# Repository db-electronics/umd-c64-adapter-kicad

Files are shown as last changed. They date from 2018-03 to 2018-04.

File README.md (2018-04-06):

# Copyright and Disclaimer
Copyright: René Richard

This documentation describes Open Hardware and is licensed under the
CERN OHL v. 1.2.

You may redistribute and modify this documentation under the terms of the
CERN OHL v.1.2. (http://ohwr.org/cernohl). This documentation is distributed
WITHOUT ANY EXPRESS OR IMPLIED WARRANTY, INCLUDING OF
MERCHANTABILITY, SATISFACTORY QUALITY AND FITNESS FOR A
PARTICULAR PURPOSE. Please see the CERN OHL v.1.2 for applicable
conditions

# C64 UMD Adapter
This KiCad project contains the Commodore 64 cartridge adapter for the [Universal Mega Dumper](https://github.com/db-electronics/Universal-Mega-Dumper).

## ID
* 0x02

Each UMD adapter contains a serial shift register with an 8bit ID.

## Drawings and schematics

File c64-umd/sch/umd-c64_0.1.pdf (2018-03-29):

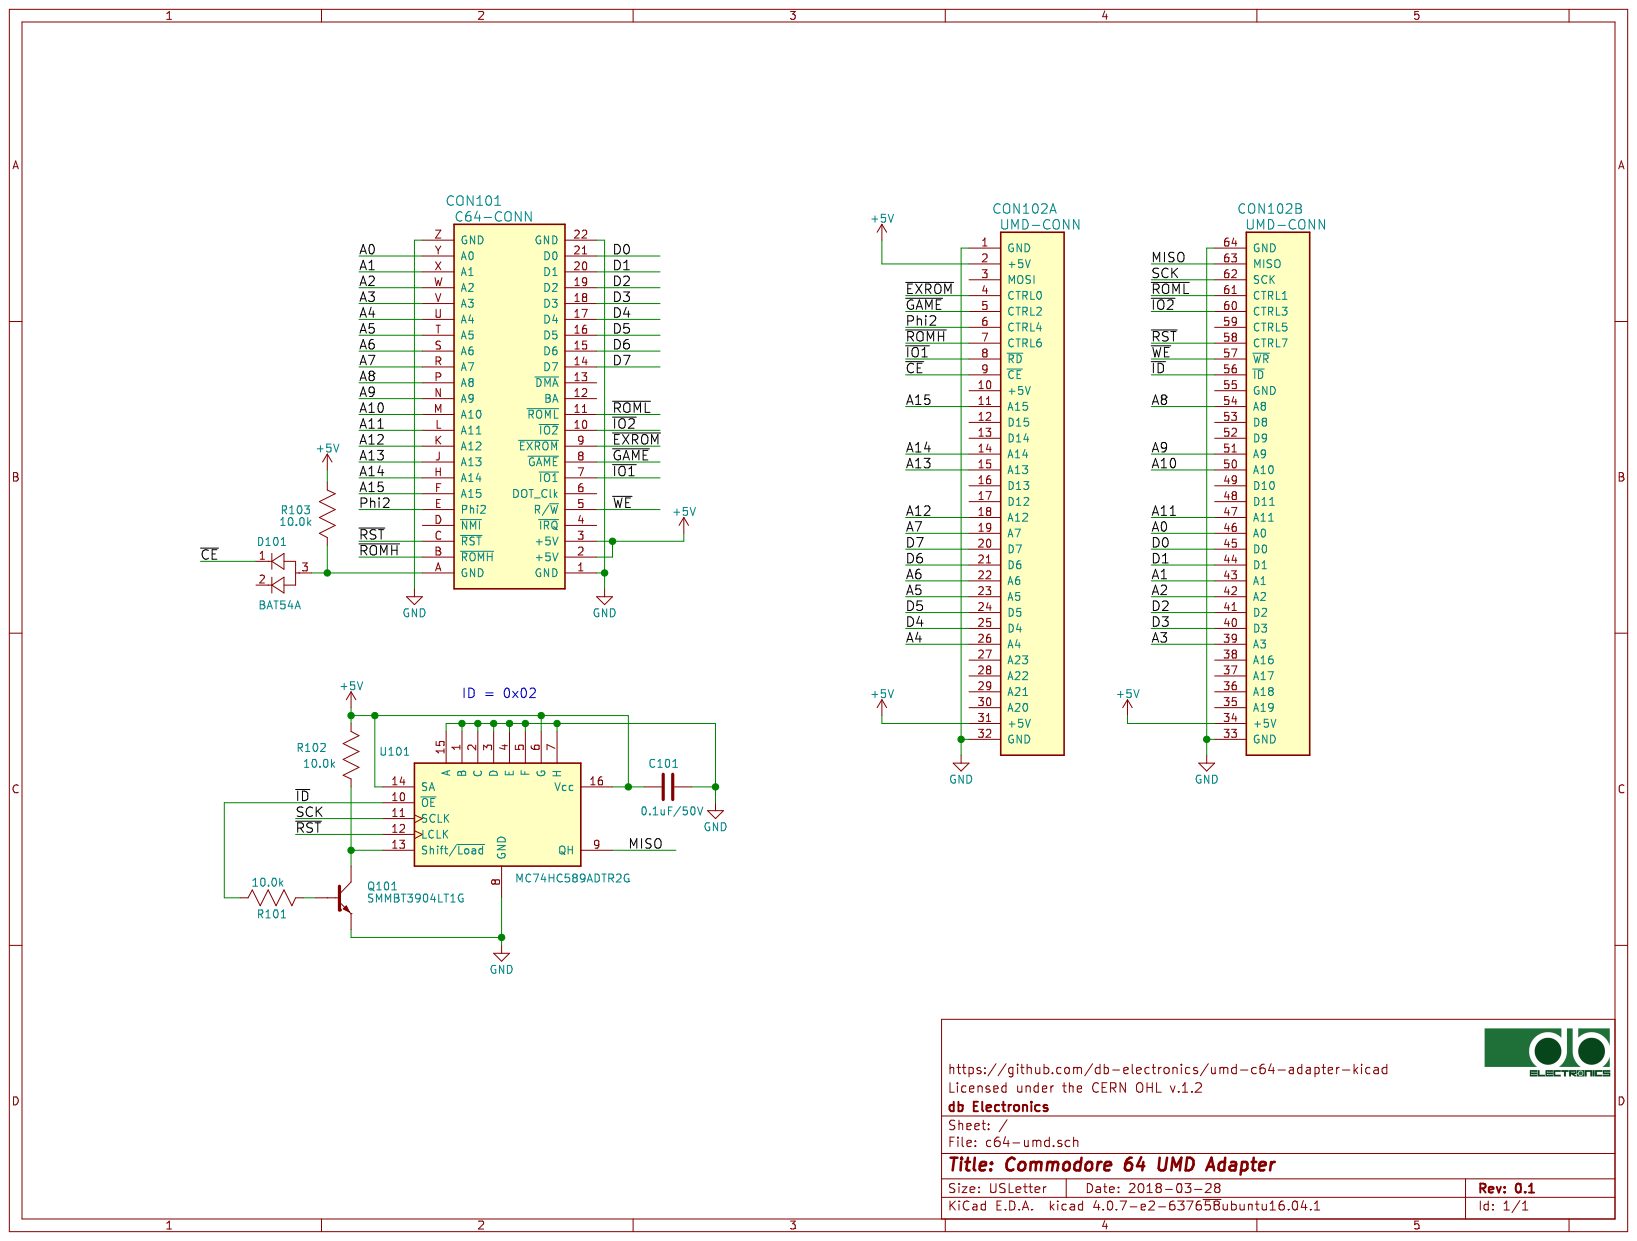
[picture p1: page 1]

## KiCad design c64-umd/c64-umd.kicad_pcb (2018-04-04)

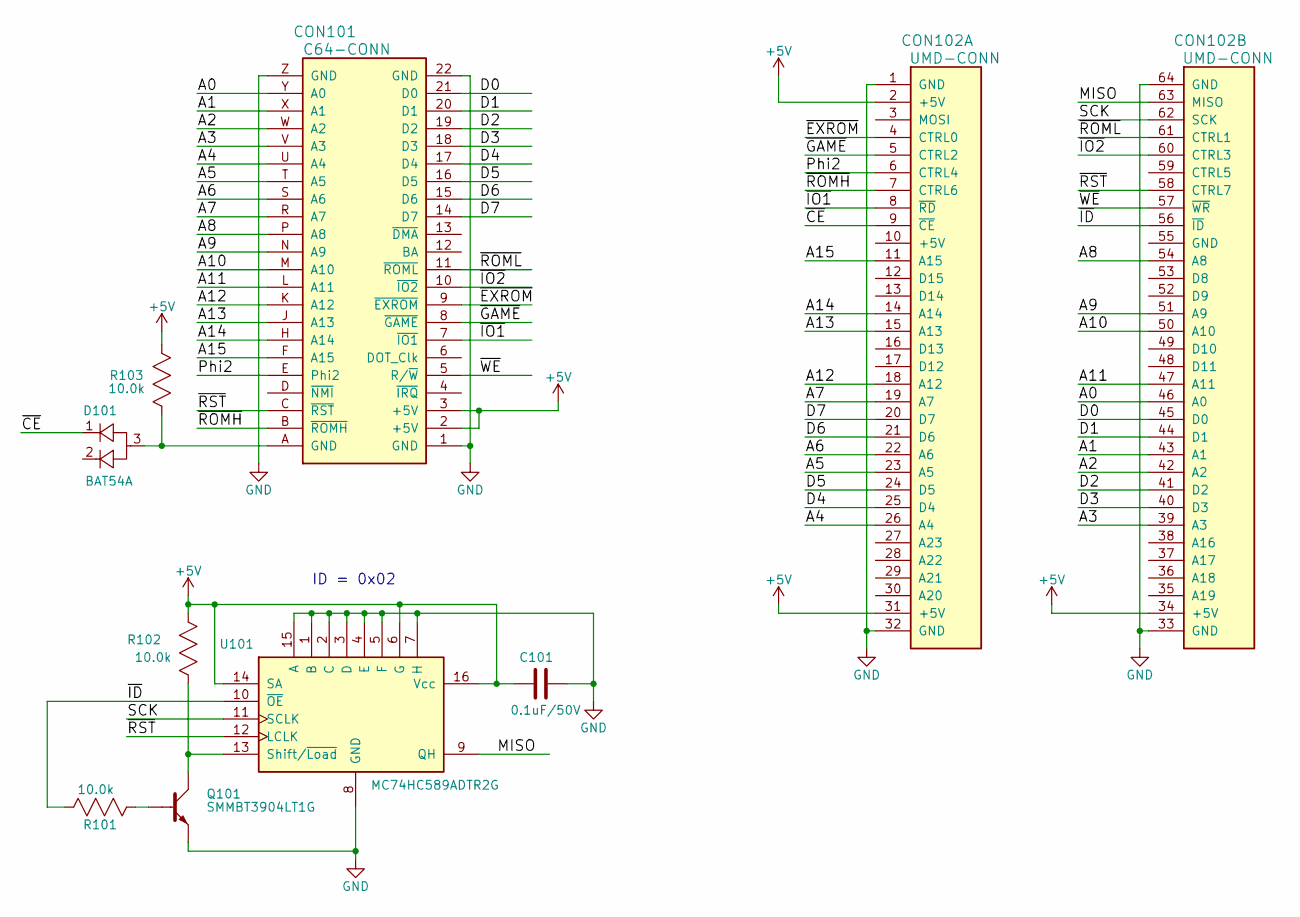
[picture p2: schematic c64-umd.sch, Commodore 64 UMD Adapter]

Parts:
C101: 0.1uF/50V; 0603; Digikey 445-5666-1-ND
CON101: C64-CONN; Digikey #ND
CON102: UMD-CONN; UMD-CONN-DIP64
D101: BAT54A; SOT23; Digikey BAT54AFSCT-ND
Q101: SMMBT3904LT1G; SOT23; Digikey SMMBT3904LT1GOSCT-ND
R101, R102, R103: 10.0k; 0603; Digikey P10.0KHCT-ND
U101: MC74HC589ADTR2G; TSSOP-16; Digikey MC74HC589ADTR2GOSCT-ND

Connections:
+5V: C101.2, CON101.2 (+5V), CON101.3 (+5V), CON102.2 (+5V), CON102.31 (+5V), CON102.34 (+5V), R102.1, R103.1, U101.6 (G), U101.14 (SA), U101.16 (Vcc)
/A0: CON101.Y (A0), CON102.46 (A0)
/A1: CON101.X (A1), CON102.43 (A1)
/A2: CON101.W (A2), CON102.42 (A2)
/A3: CON101.V (A3), CON102.39 (A3)
/A4: CON101.U (A4), CON102.26 (A4)
/A5: CON101.T (A5), CON102.23 (A5)
/A6: CON101.S (A6), CON102.22 (A6)
/A7: CON101.R (A7), CON102.19 (A7)
/A8: CON101.P (A8), CON102.54 (A8)
/A9: CON101.N (A9), CON102.51 (A9)
/A10: CON101.M (A10), CON102.50 (A10)
/A11: CON101.L (A11), CON102.47 (A11)
/A12: CON101.K (A12), CON102.18 (A12)
/A13: CON101.J (A13), CON102.15 (A13)
/A14: CON101.H (A14), CON102.14 (A14)
/A15: CON101.F (A15), CON102.11 (A15)
/D0: CON101.21 (D0), CON102.45 (D0)
/D1: CON101.20 (D1), CON102.44 (D1)
/D2: CON101.19 (D2), CON102.41 (D2)
/D3: CON101.18 (D3), CON102.40 (D3)
/D4: CON101.17 (D4), CON102.25 (D4)
/D5: CON101.16 (D5), CON102.24 (D5)
/D6: CON101.15 (D6), CON102.21 (D6)
/D7: CON101.14 (D7), CON102.20 (D7)
/MISO: CON102.63 (MISO), U101.9 (QH)
/Phi2: CON101.E (Phi2), CON102.6 (CTRL4)
/SCK: CON102.62 (SCK), U101.11 (SCLK)
/~CE: CON102.9 (~CE), D101.1
/~EXROM: CON101.9 (~EXROM), CON102.4 (CTRL0)
/~GAME: CON101.8 (~GAME), CON102.5 (CTRL2)
/~ID: CON102.56 (~ID), R101.2, U101.10 (~OE)
/~IO1: CON101.7 (~IO1), CON102.8 (~RD)
/~IO2: CON101.10 (~IO2), CON102.60 (CTRL3)
/~ROMH: CON101.B (~ROMH), CON102.7 (CTRL6)
/~ROML: CON101.11 (~ROML), CON102.61 (CTRL1)
/~RST: CON101.C (~RST), CON102.58 (CTRL7), U101.12 (LCLK)
/~WE: CON101.5 (R/~W), CON102.57 (~WR)
GND: C101.1, CON101.1 (GND), CON101.22 (GND), CON101.Z (GND), CON102.1 (GND), CON102.32 (GND), CON102.33 (GND), CON102.64 (GND), Q101.2 (E), U101.1 (B), U101.2 (C), U101.3 (D), U101.4 (E), U101.5 (F), U101.7 (H), U101.8 (GND), U101.15 (A)
unnamed: CON101.A (GND), D101.3, R103.2
unnamed: Q101.1 (B), R101.1
unnamed: Q101.3 (C), R102.2, U101.13 (Shift/~Load)

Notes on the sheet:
ID = 0x02

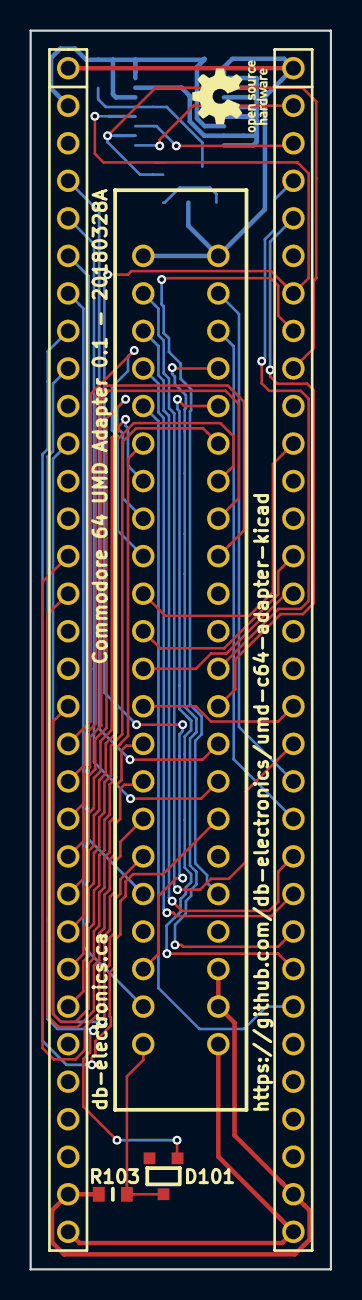
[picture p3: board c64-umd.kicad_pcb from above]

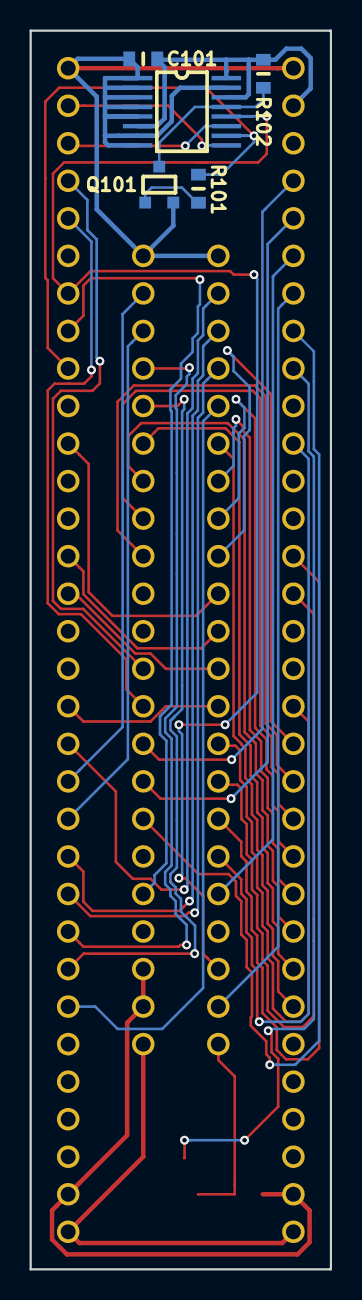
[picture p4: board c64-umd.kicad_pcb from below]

Board: 2 copper layers, 20.3 x 83.8 mm, 9 parts (5 on the bottom side), 42 nets.

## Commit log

2018-03-28 added license info
    [c64-umd.kicad_pcb, c64-umd.sch]
2018-03-28 prelim sch done
    [c64-umd.sch]
2018-03-29 pcb outline and parts layout
    [c64-umd.kicad_pcb, c64-umd.sch]
2018-03-29 prelim routing complete, review before 0.1 release
    [c64-umd.kicad_pcb, c64-umd.sch]
2018-04-04 generated 0.1 gerbers
    [c64-umd-B.Cu.gbl, c64-umd-B.Mask.gbs, c64-umd-B.SilkS.gbo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]
